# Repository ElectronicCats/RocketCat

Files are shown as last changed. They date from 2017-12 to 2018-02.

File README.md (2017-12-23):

# RocketCat: Kit of Water Rocket WiFi

<a title="By Franz Helm (book by Franz Helm from 16th century) [Public domain], via Wikimedia Commons" href="https://upload.wikimedia.org/wikipedia/commons/2/21/Rocket_cat_cropped.jpg">Rocket cat and rocket dove</a>

Fuente: Ein wahres Probiertes und Pracktisches geschriebenes Feuerbuch <br>
Autor: Franz Helm

Si tu eres un fanatico de los cohetes y deseas experimentar con electronica, WiFi y cohetes de agua, RocketCat es un kit open source para niños, adultos y todo fan que desea aprender de esta tecnologia. ¡Ciencia en acción!

### Construye y lanza un cohete
Construye tu propio cohete con solo una botella, electronica, agua y una bomba. ¡Mira cómo el cohete se eleva muy alto mientras bombeas aire hacia él! Alimentado por agua y presión de aire mientras observas todos los cambios de aceleracion, orientacion y altura en tu smartphone o computadora.

### Ciencia y aprendizaje divertidos
El Kit RocketCat es perfecto para el estudiante o el entusiasta de la ciencia. Se incluye todo lo que necesita para construir su propio cohete de agua mientras aprende sobre la tecnología.

### Todo para construir tu cohete
El kit Rocket contiene:

- 1 Botella de plástico
- 4 Aletas (una para el repuesto)
- 1 Soporte para aletas
- 1 Tapón
- 1 Conector para tapón 
- 1 Conector para bomba 
- 1 Tubo de extensión de plástico, 
- 1 Tarjeta electronica para montaje
- Modulo WiFi ESP8266
- Sensor de presion y altura BMP180
- GY-87 sensor de aceleracion, magnetrometro y giroscopio
- Instrucciones detalladas

El nombre esta inspirado en el trabajo e ilustraciones de [Franz Helm](https://en.wikipedia.org/wiki/Franz_Helm) y su **Rocket Cat**

## TODO

- Wiki con instrucciones
- Mejora de web de monitoreo
- Soporte para ESP32 and BLE

## LICENSE

Electronic Cats invierte tiempo y recursos al proporcionar este diseño de fuente abierta, por favor ayude a Electronic Cats y hardware de código abierto comprando productos de Electronic Cats.

Diseñado por Electronic Cats.

Firmware lanzado bajo una licencia de GNU AGPL v3.0. Vea el archivo LICENCIA para más información.

Hardware lanzado bajo una licencia de hardware Open CERN v1.2. Consulte el archivo LICENSE_HARDWARE para obtener más información.

Electronic Cats es una marca registrada, no la use si vende estos PCB.

7 Dic 2017

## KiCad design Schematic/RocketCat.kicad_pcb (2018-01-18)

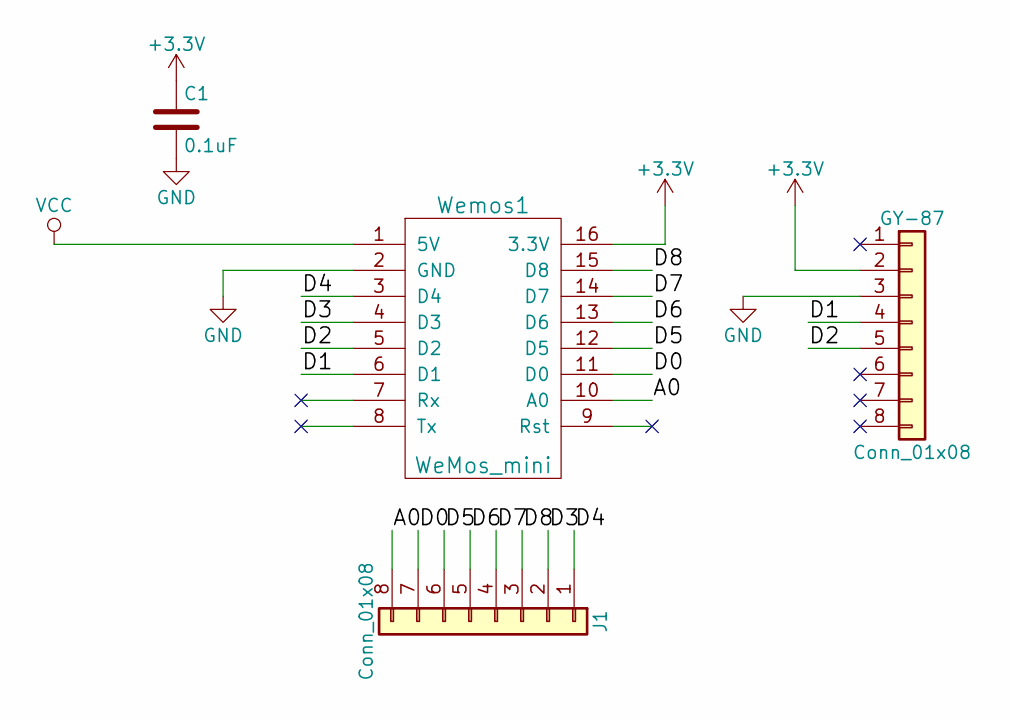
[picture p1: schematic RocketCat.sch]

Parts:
C1: 0.1uF
GY-87: Conn_01x08; Socket_Strip_Straight_1x08_Pitch2.54mm
J1: Conn_01x08; Socket_Strip_Straight_1x08_Pitch2.54mm
Wemos1: WeMos_mini; wemos-d1-mini-connectors-only

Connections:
+3V3: C1.1, GY-87.2, Wemos1.16 (3.3V)
/A0: J1.8, Wemos1.10 (A0)
/D0: J1.7, Wemos1.11 (D0)
/D1: GY-87.4, Wemos1.6 (D1)
/D2: GY-87.5, Wemos1.5 (D2)
/D3: J1.2, Wemos1.4 (D3)
/D4: J1.1, Wemos1.3 (D4)
/D5: J1.6, Wemos1.12 (D5)
/D6: J1.5, Wemos1.13 (D6)
/D7: J1.4, Wemos1.14 (D7)
/D8: J1.3, Wemos1.15 (D8)
GND: C1.2, GY-87.3, Wemos1.2 (GND)
VCC: Wemos1.1 (5V)

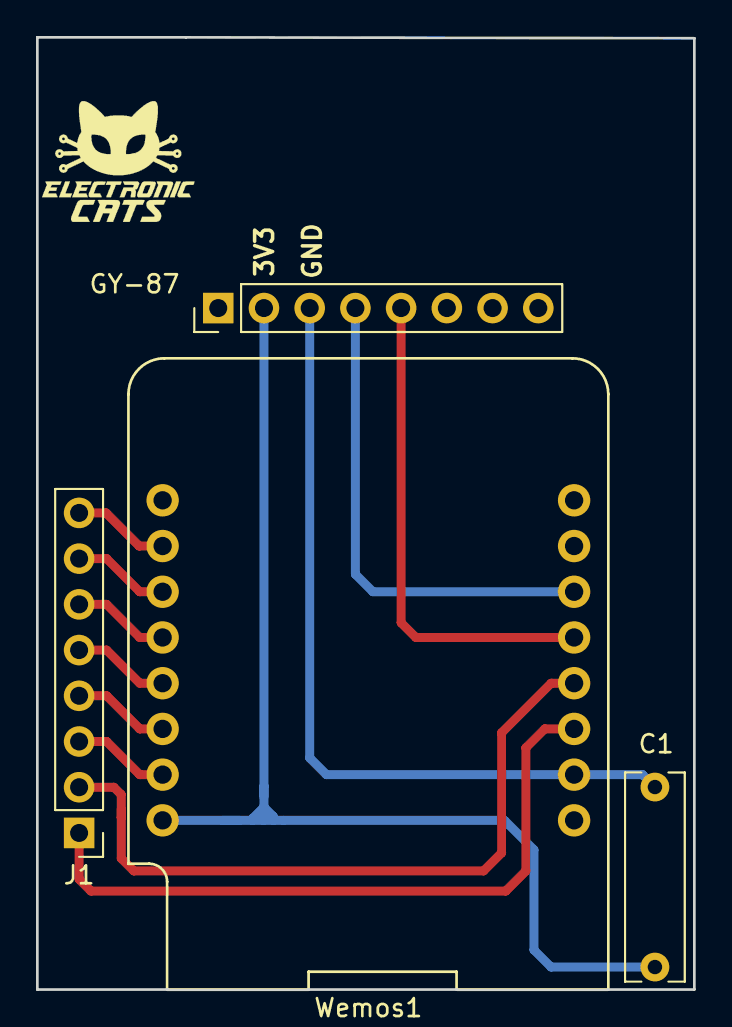
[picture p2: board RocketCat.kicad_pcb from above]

Board: 2 copper layers, 36.5 x 52.9 mm, 4 parts (0 on the bottom side), 12 nets.

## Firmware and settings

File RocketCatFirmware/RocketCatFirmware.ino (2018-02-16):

#include <Wire.h>
#include <Adafruit_Sensor.h>
#include <Adafruit_BMP085_U.h>
#include <Adafruit_HMC5883_U.h>
#include "I2Cdev.h"
#include "MPU6050.h"
#include <ESP8266WiFi.h>

Adafruit_BMP085_Unified bmp = Adafruit_BMP085_Unified(10085);

/* Assign a unique ID to this sensor at the same time */
Adafruit_HMC5883_Unified mag = Adafruit_HMC5883_Unified(12345);


// class default I2C address is 0x68
// specific I2C addresses may be passed as a parameter here
// AD0 low = 0x68 (default for InvenSense evaluation board)
// AD0 high = 0x69
MPU6050 accelgyro;
//MPU6050 accelgyro(0x69); // <-- use for AD0 high
// uncomment "OUTPUT_READABLE_ACCELGYRO" if you want to see a tab-separated
// list of the accel X/Y/Z and then gyro X/Y/Z values in decimal. Easy to read,
// not so easy to parse, and slow(er) over UART.
#define OUTPUT_READABLE_ACCELGYRO

// uncomment "OUTPUT_BINARY_ACCELGYRO" to send all 6 axes of data as 16-bit
// binary, one right after the other. This is very fast (as fast as possible
// without compression or data loss), and easy to parse, but impossible to read
// for a human.
//#define OUTPUT_BINARY_ACCELGYRO

int16_t ax, ay, az;
int16_t gx, gy, gz;


//////////////////////
// WiFi Definitions //
//////////////////////
const char WiFiAPPSK[] = "rocketcat";

WiFiServer server(80);

void setup() {
  
{
  setupWiFi();
  server.begin();
}


  Serial.begin(9600);
  Serial.println("RocketCat Iniciando"); Serial.println("");

  /* Initialise the sensor */
  if(!bmp.begin())
  {
    /* There was a problem detecting the BMP085 ... check your connections */
    Serial.print("Ooops, no BMP085 detected ... Check your wiring or I2C ADDR!");
    while(1);
  }
      // initialize device
    Serial.println("Initializing I2C devices...");
    accelgyro.initialize();

    accelgyro.setI2CMasterModeEnabled(false);
    accelgyro.setI2CBypassEnabled(true) ;
    accelgyro.setSleepEnabled(false);

    // verify connection
    Serial.println("Testing device connections...");
    Serial.println(accelgyro.testConnection() ? "MPU6050 connection successful" : "MPU6050 connection failed");

     /* Initialise the sensor */
  if(!mag.begin())
  {
    /* There was a problem detecting the HMC5883 ... check your connections */
    Serial.println(F("Ooops, no HMC5883 detected ... Check your wiring!"));
    while(1);
  }
  
}

void loop() {
 /* Get a new sensor event */ 
  sensors_event_t event;
  bmp.getEvent(&event);
 
  /* Display the results (barometric pressure is measure in hPa) */
  if (event.pressure)
  {
    /* Display atmospheric pressue in hPa */
    Serial.print("Pressure:    ");
    Serial.print(event.pressure);
    Serial.println(" hPa");
    
    /* Calculating altitude with reasonable accuracy requires pressure    *
     * sea level pressure for your position at the moment the data is     *
     * converted, as well as the ambient temperature in degress           *
     * celcius.  If you don't have these values, a 'generic' value of     *
     * 1013.25 hPa can be used (defined as SENSORS_PRESSURE_SEALEVELHPA   *
     * in sensors.h), but this isn't ideal and will give variable         *
     * results from one day to the next.                                  *
     *                                                                    *
     * You can usually find the current SLP value by looking at weather   *
     * websites or from environmental information centers near any major  *
     * airport.                                                           *
     *                                                                    *
     * For example, for Paris, France you can check the current mean      *
     * pressure and sea level at: http://bit.ly/16Au8ol                   */
     
    /* First we get the current temperature from the BMP085 */
    float temperature;
    bmp.getTemperature(&temperature);
    Serial.print("Temperature: ");
    Serial.print(temperature);
    Serial.println(" C");

    /* Then convert the atmospheric pressure, and SLP to altitude         */
    /* Update this next line with the current SLP for better results      */
    float seaLevelPressure = SENSORS_PRESSURE_SEALEVELHPA;
    Serial.print("Altitude:    "); 
    Serial.print(bmp.pressureToAltitude(seaLevelPressure,
                                        event.pressure)); 
    Serial.println(" m");
    Serial.println("");
  }
  else
  {
    Serial.println("Sensor error");
  }

      // read raw accel/gyro measurements from device
    accelgyro.getMotion6(&ax, &ay, &az, &gx, &gy, &gz);

    #ifdef OUTPUT_READABLE_ACCELGYRO
        // display tab-separated accel/gyro x/y/z values
        Serial.print("a/g:\t");
        Serial.print(ax); Serial.print("\t");
        Serial.print(ay); Serial.print("\t");
        Serial.print(az); Serial.print("\t");
        Serial.print(gx); Serial.print("\t");
        Serial.print(gy); Serial.print("\t");
        Serial.println(gz);
    #endif

    #ifdef OUTPUT_BINARY_ACCELGYRO
        Serial.write((uint8_t)(ax >> 8)); Serial.write((uint8_t)(ax & 0xFF));
        Serial.write((uint8_t)(ay >> 8)); Serial.write((uint8_t)(ay & 0xFF));
        Serial.write((uint8_t)(az >> 8)); Serial.write((uint8_t)(az & 0xFF));
        Serial.write((uint8_t)(gx >> 8)); Serial.write((uint8_t)(gx & 0xFF));
        Serial.write((uint8_t)(gy >> 8)); Serial.write((uint8_t)(gy & 0xFF));
        Serial.write((uint8_t)(gz >> 8)); Serial.write((uint8_t)(gz & 0xFF));
    #endif

  mag.getEvent(&event);
     /* Display the results (magnetic vector values are in micro-Tesla (uT)) */
  Serial.print("X: "); Serial.print(event.magnetic.x); Serial.print("  ");
  Serial.print("Y: "); Serial.print(event.magnetic.y); Serial.print("  ");
  Serial.print("Z: "); Serial.print(event.magnetic.z); Serial.print("  ");Serial.println("uT");

  // Hold the module so that Z is pointing 'up' and you can measure the heading with x&y
  // Calculate heading when the magnetometer is level, then correct for signs of axis.
  float heading = atan2(event.magnetic.y, event.magnetic.x);
  
  // Once you have your heading, you must then add your 'Declination Angle', which is the 'Error' of the magnetic field in your location.
  // Find yours here: http://www.magnetic-declination.com/
  // Mine is: -13* 2' W, which is ~13 Degrees, or (which we need) 0.22 radians
  // If you cannot find your Declination, comment out these two lines, your compass will be slightly off.
  float declinationAngle = +5.22;
  heading += declinationAngle;
  
  // Correct for when signs are reversed.
  if(heading < 0)
    heading += 2*PI;
    
  // Check for wrap due to addition of declination.
  if(heading > 2*PI)
    heading -= 2*PI;
   
  // Convert radians to degrees for readability.
  float headingDegrees = heading * 180/M_PI; 
  
  Serial.print("Heading (degrees): "); Serial.println(headingDegrees);

  delay(500);


//////////////////wificlient////////////
    {
  // Check if a client has connected
  WiFiClient client = server.available();
  if (!client) {
    return;
  }

  // Read the first line of the request
  String req = client.readStringUntil('\r');
  Serial.println(req);
  client.flush();

 // if

  client.flush();

  // Prepare the response. Start with the common header:
  String s = "HTTP/1.1 200 OK\r\n";
  s += "Content-Type: text/html\r\n\r\n";
  s += "<!DOCTYPE HTML>\r\n<html>\r\n";
  s += "<meta http-equiv='refresh' content='0.1' >";
  s += "<meta http-equiv='repeat' content='0.1'>";
  
  if  (req.indexOf("/read"))
  { // If we're reading pins, print out those values:
    s += "<html>";
    s += "<head>";
    s += "</head>";
    s += "<body>"; 
    s += "<h1>RocketCat</h1>";       
    s += "Pressure, Temperature and Altitude: ";
 bmp.getEvent(&event);
    float temperature;
    bmp.getTemperature(&temperature);
    float seaLevelPressure = SENSORS_PRESSURE_SEALEVELHPA;
    s += "<br>";
    s += "Pressure= ";
    s += (event.pressure);
    s += " hPa";
    s += "<br>";
    s += "Temperature= ";
    s += (temperature);
    s += " &deg C";
    s += "<br>";
    s += "Altitude= ";
    s += (bmp.pressureToAltitude(seaLevelPressure, event.pressure));
    s += " m";
    s += "<br><br>"; // Go to the next line.    
    s += "AccelGyroMetter: ";
    accelgyro.getAcceleration(&ax, &ay, &az);
    accelgyro.getRotation(&gx, &gy, &gz);
    s += "<br>";
    s += "Acceleration= ";
    s += "AX= ";
    s += ax;
    s += "&nbsp&nbsp&nbsp";
    s += "AY= ";
    s += ay;
    s += "&nbsp&nbsp&nbsp";
    s += "AZ= ";
    s += az;
    s += "<br>";
    s += "Rotation= ";
    s += "GX= ";
    s += gx;
    s += "&nbsp&nbsp&nbsp";
    s += "GY= ";
    s += gy;
    s += "&nbsp&nbsp&nbsp";
    s += "GZ= ";
    s += gz;
    s += "<br><br><br>";
    s += "MagnetoMetter: ";
    s += "<br>";
    mag.getEvent(&event);
    float heading = atan2(event.magnetic.y, event.magnetic.x);
    float declinationAngle = +5.22;
     heading += declinationAngle;  
  // Correct for when signs are reversed.
  if(heading < 0)
    heading += 2*PI;
    // Check for wrap due to addition of declination.
  if(heading > 2*PI)
    heading -= 2*PI;
    // Convert radians to degrees for readability.
    float headingDegrees = heading * 180/M_PI; 
    s += "X= ";
    s += event.magnetic.x;
    s += "&deg";
    s += "&nbsp&nbsp&nbsp";
    s += "Y= ";
    s += event.magnetic.y;
    s += "&deg";
    s += "&nbsp&nbsp&nbsp";
    s += "Z= ";
    s += event.magnetic.z;
    s += "&deg";
    s += "<br>";
    s += "Heading= ";
    s += headingDegrees;
    s += "&deg";
    s += "<br>";
    s += "<html>";
  }
  else
  {
    s += "Invalid Request.<br> Try /read.";
  }
  s += "</html>\n";

  // Send the response to the client
  client.print(s);
  delay(1);
  Serial.println("Client disonnected");

  // The client will actually be disconnected 
  // when the function returns and 'client' object is detroyed
}
}
void setupWiFi()
{
  WiFi.mode(WIFI_AP);

  // Do a little work to get a unique-ish name. Append the
  // last two bytes of the MAC (HEX'd) to "Thing-":
  uint8_t mac[WL_MAC_ADDR_LENGTH];
  WiFi.softAPmacAddress(mac);
  String macID = String(mac[WL_MAC_ADDR_LENGTH - 2], HEX) +
                 String(mac[WL_MAC_ADDR_LENGTH - 1], HEX);
  macID.toUpperCase();
  String AP_NameString = "Rocket Cat " + macID;

  char AP_NameChar[AP_NameString.length() + 1];
  memset(AP_NameChar, 0, AP_NameString.length() + 1);

  for (int i=0; i<AP_NameString.length(); i++)
    AP_NameChar[i] = AP_NameString.charAt(i);

  WiFi.softAP(AP_NameChar, WiFiAPPSK);
}

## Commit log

2017-12-08 Agregado Sketch Arduino
2017-12-08 Agregado sensor BMP180
2017-12-11 Agregado HMC5883
    Pequeño porblema con "Y" y "Z" de magsensor
2017-12-12 Magnetometro funcionando
2017-12-19 Incluido el web y los datos.
    Falta mostrar datos en web.
2017-12-22 Incluyendo el refresh
    Refresh
2017-12-22 Agregando Presion, Temperatura y Altitud.
2017-12-22 Agregando magsensor
    al igual que x y z esta los datos y agregados a html
2017-12-22 Un plus, Agregando imagen
    aun falta guardarlo en el ESP8266
2017-12-23 Actualizacion de README
2018-01-08 Agregado esquematico
    [RocketCat.kicad_pcb, RocketCat.sch]
2018-01-09 Esquematico de WeMos PCB
    Aun falta poner los pines
    [_saved_RocketCat.sch]
2018-01-09 Net del esquematico
    Agregado WeMos para simulacion
2018-01-10 Esquematico de Wemos
    Denuevo por error de no visualizacion
    [RocketCat.sch]
2018-01-10 Todods lo datos del esquematico y pcb
    [RocketCat.kicad_pcb]
2018-01-10 Agregado Bateria y gy 87
    en lo de la pbc me falta un pista, lo podrias poner pof favor xd
    [RocketCat.kicad_pcb, RocketCat.sch]
2018-01-12 PCB Lista
    Checar si no tengo nada mal
    [RocketCat.kicad_pcb, RocketCat.sch]
2018-01-15 Pcb aun no lista. v.0.1
    Se redujo el espacio, para no desperdiciarlo.
    Arreglo de pistas de 0.25mm a 0.3mm
    Espacio definido para el GY87
    [RocketCat.kicad_pcb]
2018-01-18 fix size and tracks remove MCP charger
    [RocketCat.kicad_pcb, RocketCat.sch]
2018-01-18 Añadido logo de EC
    [RocketCat.kicad_pcb]
2018-02-16 Actualizado Webserver
    Se disminuyo el refresh a 0.1 seg, para obtener datos mas rapido.
